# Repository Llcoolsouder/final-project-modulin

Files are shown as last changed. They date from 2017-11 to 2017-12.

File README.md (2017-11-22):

# Modulin
A _modulin_ is an electronic, violin-esque, musical instrument. The original modulin was created by Martin Molin of Wintergatan.
Footage of the orignal instrument can be found [here](https://www.youtube.com/watch?v=MUdWeBYe3GY). 

Created by:
Lonnie L. Souder II

final-project-modulin created by GitHub Classroom

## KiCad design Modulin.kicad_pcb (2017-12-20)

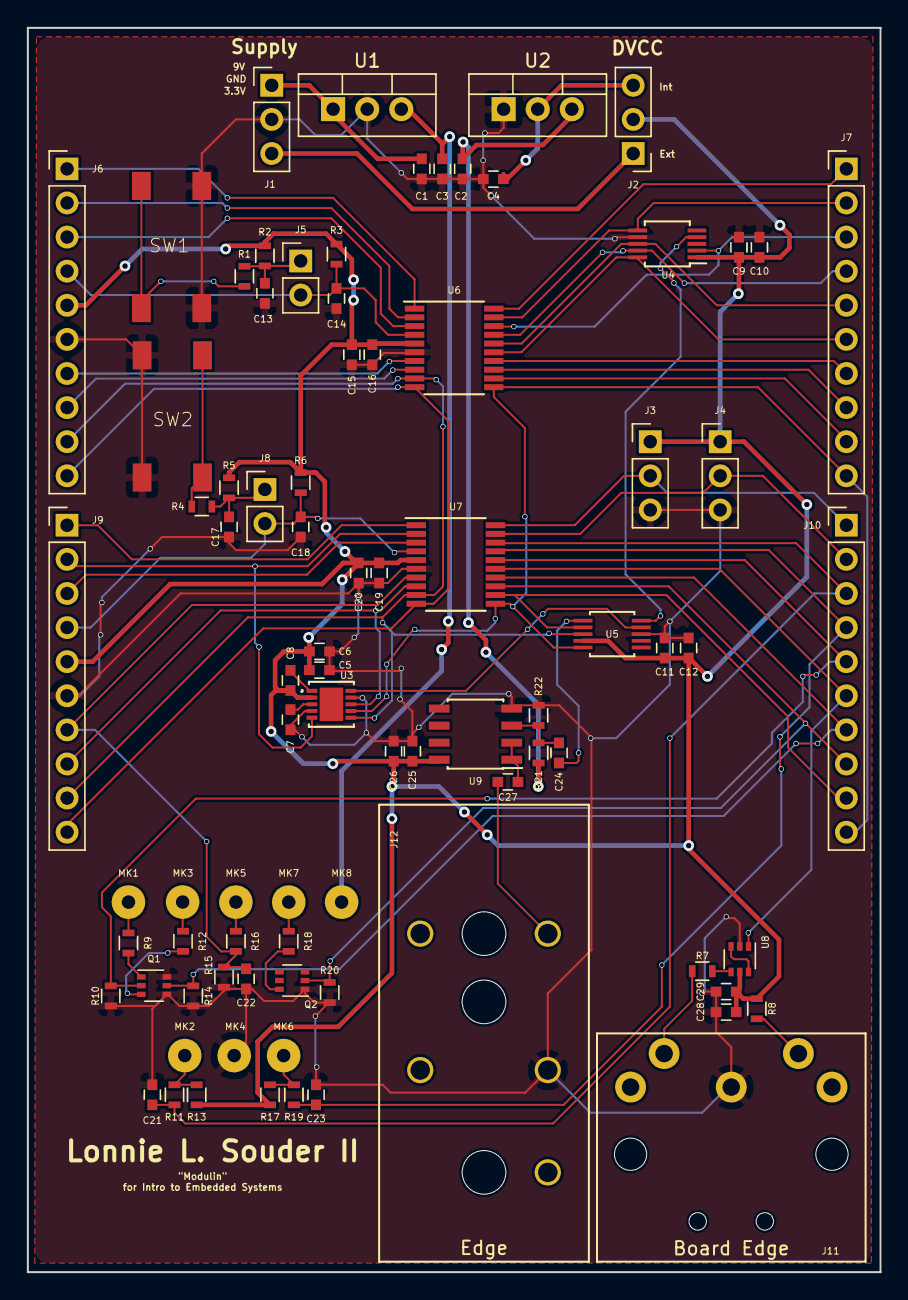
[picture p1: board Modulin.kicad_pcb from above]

Board: 2 copper layers, 63.5 x 92.7 mm, 84 parts (0 on the bottom side), 64 nets.

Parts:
C1, C2, C16, C20: 100n; C_0603
C3, C4, C6: 10u; C_0603
C5, C7, C9: 0.1u; C_0603
C8, C12, C13, C17, C21, C22, C23, C26, C29: 10n; C_0603
C10, C11, C15, C19, C24, C25, C27, C28: 1u; C_0603
C14, C18: 1n; C_0603
J1, J2: Conn_01x03_Male; Pin_Header_Straight_1x03_Pitch2.54mm
J3, J4: Conn_01x03_Female; Pin_Header_Straight_1x03_Pitch2.54mm
J5, J8: Conn_01x02_Male; Pin_Header_Straight_1x02_Pitch2.54mm
J6, J7, J9, J10: Conn_01x10_Male; Pin_Header_Straight_1x10_Pitch2.54mm
J11: DIN-5_180degree; SDS-50J
J12: Audio-Jack-2; SN37A14B
MK1, MK2, MK3, MK4, MK5, MK6, MK7, MK8: Mounting_Hole_PAD; SolderWirePad_single_1mmDrill
Q1, Q2: DMN63D8LDW-7; SOT-363_SC-70-6
R1, R2, R4, R5, R11, R13, R15, R16, R17, R19: 10k; R_0603
R3, R6: 47; R_0603
R7, R8: 220; R_0603
R9: 320; R_0603
R10, R14, R20: 1M; R_0603
R12, R18: 170; R_0603
R21, R22: 500k; R_0603
SW1, SW2: SW_Push; FSM2JSMAATR
U1: LM7805CT; TO-220-3_Vertical
U2: LD1117V33; TO-220-3_Vertical
U3: AD9837BCPZ-RL7
U4: MCP48FVB21-E/UN; MSOP-10_3x3mm_Pitch0.5mm
U5: MAX4587EUB+; MAX4587EUB&plus_
U6, U7: MSP430FR2311IPW20R; TSSOP-20_4.4x6.5mm_Pitch0.65mm
U8: NL27WZ04DFT1G; SOT-363_SC-70-6
U9: TSH22IDT; SOIC-8_3.9x4.9mm_Pitch1.27mm

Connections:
+3V3: J1.3, J2.1
+5V: C3.1, MK8.1, U1.3
+9V: C1.1, C2.1, J1.1, R21.1, U1.1, U2.3
/AudioOut/AudioOut: C24.2, U5.1
/FR2311_setup1/P1.0: J6.2, U6.2
/FR2311_setup1/P1.1: J6.1, U6.1
/FR2311_setup1/P1.2: J7.1, U6.20
/FR2311_setup1/P1.3: J7.2, U4.6, U6.19
/FR2311_setup1/P1.4: J7.3, U4.2, U6.18
/FR2311_setup1/P1.5: J7.4, U4.9, U6.17
/FR2311_setup1/P1.6: J7.5, U4.8, U6.16
/FR2311_setup1/P1.7: J7.6, U4.10, U6.15
/FR2311_setup1/P2.0: J7.7, U6.14
/FR2311_setup1/P2.1: J7.8, U6.13
/FR2311_setup1/P2.2: J7.9, U6.12
/FR2311_setup1/P2.3: J7.10, J10.10, U3.7, U5.5, U6.11, U7.11
/FR2311_setup1/P2.4: J6.9, J9.9, U3.6, U5.3, U6.9, U7.9
/FR2311_setup1/P2.5: J6.10, J9.10, U6.10, U7.10
/FR2311_setup1/P2.6: J6.8, U6.8
/FR2311_setup1/P2.7: J6.7, U6.7
/FR2311_setup1/TEST: J6.3, U6.3
/FR2311_setup1/~RST: C14.2, J5.2, J6.4, R3.1, U6.4
/FR2311_setup2/P1.0: J9.2, U3.5, U7.2
/FR2311_setup2/P1.1: J9.1, U7.1
/FR2311_setup2/P1.2: J3.2, J10.1, U7.20
/FR2311_setup2/P1.3: J4.2, J10.2, U7.19
/FR2311_setup2/P1.6: J10.5, Q1.2, R10.1, U7.16
/FR2311_setup2/P2.0: J10.7, Q1.5, R14.1, U7.14
/FR2311_setup2/P2.1: J10.8, Q2.2, R20.1, U7.13
/FR2311_setup2/P2.2: J10.9, U5.2, U7.12
/FR2311_setup2/P2.6: J9.8, U3.8, U7.8
/FR2311_setup2/TEST: J9.3, U7.3
/FR2311_setup2/~RST: C18.2, J8.2, J9.4, R6.1, U7.4
/MIDI_out/DataOut: J10.6, U7.15, U8.1
/RGB_Encoder/A: C21.1, J10.3, R11.2, U7.18
/RGB_Encoder/B: C23.1, J10.4, R19.1, U7.17
/RGB_Encoder/Btn: C22.1, J9.7, R15.1, R16.2, U7.7
DVCC: C5.1, C6.1, C8.1, C9.1, C10.1, C11.1, C12.1, C15.1, C16.1, C19.1, C20.1, C25.2, C26.1, C28.1, C29.1, J2.2, J3.1, J4.1, J6.5, J9.5, R2.1, R3.2, R5.1, R6.2, R8.1, R13.1, R17.2, U3.2, U4.1, U5.4, U6.5, U7.5, U8.5, U9.8
GNDD: C1.2, C2.2, C3.2, C4.2, C5.2, C6.2, C7.2, C9.2, C10.2, C11.2, C12.2, C13.2, C14.1, C15.2, C16.2, C17.2, C18.1, C19.2, C20.2, C21.2, C22.2, C23.2, C25.1, C26.2, C28.2, C29.2, J1.2, J3.3, J4.3, J6.6, J9.6, J11.2, J12.2, MK4.1, Q1.4, Q1.6, Q2.1, R10.2, R14.2, R15.2, R20.2, R22.2, SW1.1, SW2.1, U1.2, U2.1, U3.4, U3.9, U4.7, U5.8, U6.6, U7.6, U8.2, U9.4
unnamed: C4.1, J2.3, U2.2
unnamed: C7.1, U3.3
unnamed: C8.2, U3.1
unnamed: C13.1, J5.1, R1.1, R2.2
unnamed: C17.1, J8.1, R4.1, R5.2
unnamed: C24.1, R21.2, R22.1, U9.3
unnamed: C27.1, J12.1
unnamed: C27.2, U9.1, U9.2
unnamed: J11.4, R8.2
unnamed: J11.5, R7.1
unnamed: MK1.1, R9.1
unnamed: MK2.1, R11.1, R13.2
unnamed: MK3.1, R12.1
unnamed: MK5.1, R16.1
unnamed: MK6.1, R17.1, R19.2
unnamed: MK7.1, R18.1
unnamed: Q1.1, R9.2
unnamed: Q1.3, R12.2
unnamed: Q2.6, R18.2
unnamed: R1.2, SW1.2
unnamed: R4.2, SW2.2
unnamed: R7.2, U8.4
unnamed: U3.10, U5.9
unnamed: U4.4, U5.10
unnamed: U8.3, U8.6

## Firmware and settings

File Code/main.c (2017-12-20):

#include <msp430.h> 

#include "SPILib.h"

/**
 * main.c
 */

/*
void toggleRegister(int* reg, int bit){
	*reg ^= bit;
}
*/

const struct Pin p1_0 = {&P1OUT, BIT0};

char messageA[6] = {0x00, 0x01, 0x02, 0x03, 0x04, 0x05};
char messageB = 0x55;

int main(void)
{
	WDTCTL = WDTPW | WDTHOLD;	// stop watchdog timer

	// GPIO init
	P1DIR |= BIT0;
	P1OUT &= ~BIT0;	// LED off
	P1DIR &= ~BIT1;	// set 1.1 to input for button
	P1REN |= BIT1;	// enable resistor
	P1OUT |= BIT1;	// pull up resistor on button
	P1IE |= BIT1;
	P1IES |= BIT1;	// set interrupt on falling edge

	initUCB0_master();
	initWaveGen();

	// Disable the GPIO power-on default high-impedance mode to activate
	// previously configured port settings
	PM5CTL0 &= ~LOCKLPM5;

	_BIS_SR(GIE);	// enable global interrupt

	while (1) {
		//sendBytes(p1_0, message, 3);
		//sendByte(p1_0, messageB);
		//__delay_cycles(100000000);
	}

	return 0;
}



/* ########################################################
 * ISRs
 * ########################################################*/


#pragma vector = PORT1_VECTOR
__interrupt void PORT_1(void) {
	//toggleRegister(&P1OUT, BIT0);
	setFrequency(440);
	//messageB++;
	P1IFG &= ~BIT1;
}

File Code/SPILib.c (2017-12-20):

/*
*	This is a library of fuctions to communicate over SPI
*	on the MSP430FR2311. 
*
*	The applications of this library are specific
*	to the Modulin project for Rowan University's "Introduction to
*	Embedded Systems." As such, this is in no way a comprehensive or
*	universal library for all projects using the eUSCI modules.
*
*	Lonnie L. Souder II
*	Undergraduate
*	Rowan University,
*	Department of Electrical & Computer Engineering
*	12/01/2017
*/

#include <msp430.h>
#include "SPILib.h"


void initUCB0_master() {
	//Configure P2.3, P2.4, and P2.5 for SPI
	P2SEL0 |= BIT3 | BIT4 | BIT5;
	SYSCFG2 |= USCIBRMP;                      // eUSCI_B0 port remapped to P2.3-P2.5
	UCB0CTLW0 |= UCSWRST;
	UCB0CTLW0 |= UCMST | UCSYNC | UCSSEL_2;
	UCB0CTLW0 &= ~UCSWRST;
	UCB0BR0 = 17;		//Set baud rate to 57600
}


void initUCB0_slave() {
	//Configure P2.3, P2.4, and P2.5 for SPI
	P2SEL0 |= BIT3 | BIT4 | BIT5;
	SYSCFG2 |= USCIBRMP;                      // eUSCI_B0 port remapped to P2.3-P2.5
	UCB0CTLW0 |= UCSWRST;
	UCB0CTLW0 |= UCSYNC | UCSSEL_2;
	UCB0CTLW0 &= ~UCSWRST;
	UCB0BR0 = 17;		//Set baud rate to 57600
}


void sendByte(const struct Pin cs, char message) {
	*cs.reg &= ~cs.bit;				// Select device
	while (!(UCB0IFG & UCTXIFG));	// Wait until TX buf is ready
	UCB0TXBUF = message;			// Send message
	while (!(UCB0IFG & UCTXIFG));	// Wait until message is sent
	*cs.reg |= cs.bit;				// Unselect device
}


void sendBytes(const struct Pin cs, char* message, int size) {
	*cs.reg &= ~cs.bit;					// Select device
	int i;
	char* start = message;				// Mark start of message
	for (i = 0; i <= size; i++){
		while (!(UCB0IFG & UCTXIFG));	// Wait until TX buf is ready
		UCB0TXBUF = *message;			// Send message
		while (!(UCB0IFG & UCTXIFG));	// Wait until message is sent
		message++;
	}
	message = start;
	*cs.reg |= cs.bit;					// Select device
}


// Wave Generator
const struct Pin p2_6 = {&P2OUT, BIT6};			// Chip Select
char reset[2] = {0b00100001, 0b00001010};	// Message to reset chip
char set[2] = {0b00100000, 0b00001010};	// Message to take chip out of reset mode

void initWaveGen() {
	P1SEL1 |= BIT0;	// Select SMCLK output
	P1DIR |= BIT0;
	P2OUT |= BIT6;	// Set to output, idle high
	P2DIR |= BIT6;
	sendBytes(p2_6, reset, 2);
	sendBytes(p2_6, set, 2);
}


void setFrequency(int freq) {
// fo = f_MCLK/2^28 * FREQREG
// fo = 1M/2^28 * FREQREG
// FREQREG = 268 * fo
int fo = freq * 268;	// Get reg value
int foLSB = (fo & 0x03FF) | 0x4000;
int foMSB = ((fo & 0x0B00) >> 14) | 0x4000;
char fmessage[6] = {0b00100000, 0b00101010,				// Turns on output (triangle wave)
					(foLSB & 0x00FF), (foLSB & 0xFF00), // Sets FREQ0 LSB
					(foMSB & 0x00FF), (foMSB & 0xFF00)};// Sets FREQ0 MSB
sendBytes(p2_6, fmessage, 6);
}

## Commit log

2017-11-16 PCB schematic started
    [Modulin.kicad_pcb, Modulin.sch]
2017-11-17 Schematic for JUST making sound.
    [Modulin.sch]
2017-11-21 Moving towards distributed architecture and heirarchical schematic
    [FR2311_setup.sch, Modulin.sch]
2017-11-21 Added sheet for MIDI out
    [FR2311_setup.sch, MIDI_out.sch, Modulin.sch]
2017-11-21 update to MIDI out sheet
    [FR2311_setup.sch, MIDI_out.sch, Modulin.sch]
2017-11-22 Added circuit for encoder
    [FR2311_setup.sch, MIDI_out.sch, Modulin.sch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]
2017-11-22 Finished Rev1 schematic and assigned most footprints
    [AudioOut.sch, FR2311_setup.sch, MIDI_out.sch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]
2017-11-23 Associated all footprints except jacks
    [Modulin.sch]
2017-11-23 Created all footprints. Started TimerLib
2017-11-26 Finished board Rev 1
    [AudioOut.sch, FR2311_setup.sch, MIDI_out.sch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]
2017-11-26 Halfway through layout. Started libraries.
    [AudioOut.sch, FR2311_setup.sch, MIDI_out.sch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]
2017-11-27 Created Gerbers
    [09342-03_souderl9_0_1.drl, 09342-03_souderl9_0_1.gbl, 09342-03_souderl9_0_1.gbo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]
2017-12-08 Tested basic functions of SPILib
    [09342-03_souderl9_0_1.drl, 09342-03_souderl9_0_10.drl, 09342-03_souderl9_0_10.gbl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]
2017-12-10 Fixed 3D models
    [Modulin.kicad_pcb]
2017-12-20 Started Modulin CCS project. Added multi-byte message for SPI

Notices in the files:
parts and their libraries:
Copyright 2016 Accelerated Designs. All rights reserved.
